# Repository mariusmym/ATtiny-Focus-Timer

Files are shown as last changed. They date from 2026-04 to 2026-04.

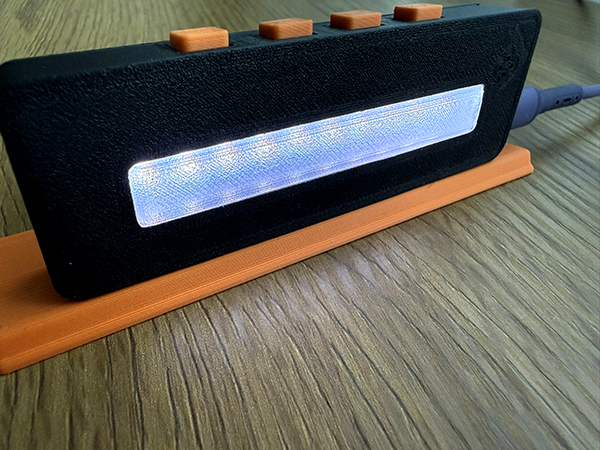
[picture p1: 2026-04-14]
images/IMG_0689.jpg

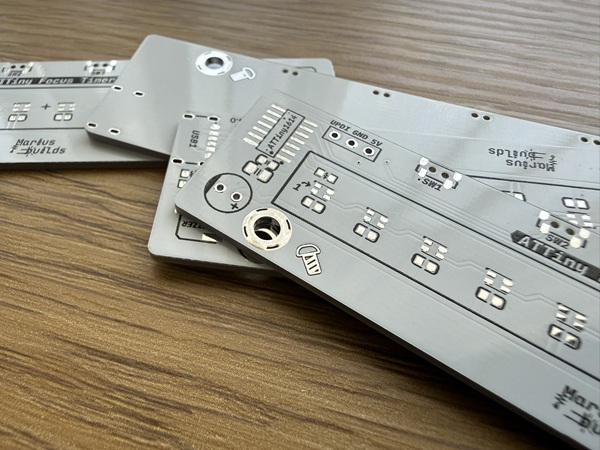
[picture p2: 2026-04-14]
images/IMG_0471.JPEG

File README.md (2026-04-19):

# ATTiny Focus Timer

A minimal, distraction-free focus timer built around the **ATtiny1614** microcontroller. Press a button, pick a duration, and get back to work - 10 WS2812B LEDs show your progress as a filling bar, then gently pulse and beep when time is up.

Created by **@marius.builds**

FocusTimer

---

## How It Works

The timer cycles through four states:

| State | LEDs | Sound |
|---|---|---|
| **Idle** | All LEDs glow white at low brightness | — |
| **Running** | Green progress bar fills one LED at a time | — |
| **Completed** | All LEDs pulse green (20 s grace period) | Finish melody (bee-beep-bee-beep) |
| **Alerting** | All LEDs pulse red | Short beep every 2 seconds |

**Buttons:**
- **In Idle** — each of the 4 buttons starts a preset timer (10 / 20 / 30 / 60 min).
- **In Running** — any button cancels and resets.
- **In Completed or Alerting** — any button acknowledges and returns to Idle.

## Hardware

| Component | Qty | Notes |
|---|---|---|
| ATtiny1614 | 1 | Programmed via megaTinyCore + UPDI |
| WS2812B / NeoPixel LEDs | 10 | Directly driven from PA3 |
| Tactile push buttons | 4 | Connected to PB0–PB3, using internal pull-ups |
| Passive piezo buzzer | 1 | Driven from PA6 via `tone()` |



### Pin Mapping

```
PA3  →  NeoPixel data
PA6  →  Piezo buzzer
PB0  →  Button 1  (10 min)
PB1  →  Button 2  (20 min)
PB2  →  Button 3  (30 min)
PB3  →  Button 4  (60 min)
```

## Software

### Dependencies

- **[megaTinyCore](https://github.com/SpenceKonde/megaTinyCore)** — Arduino core for modern tinyAVR (ATtiny x04/x14/x24 series)
- **tinyNeoPixel_Static** — included with megaTinyCore; lightweight NeoPixel driver for tinyAVR

### Building & Flashing

1. Install **megaTinyCore** via the Arduino IDE Boards Manager.
2. Select **ATtiny1614** as the target board.
3. Set the programmer to **CH340 UPDI** (or whichever UPDI method you use).
4. Open `ATTiny-FocusTimer-V2_1.ino` and upload.

### Configuration

All tunable parameters live at the top of the sketch — no need to dig through logic:

```c
// Timer durations (minutes)
TIMER_1_MINUTES  = 10;
TIMER_2_MINUTES  = 20;
TIMER_3_MINUTES  = 30;
TIMER_4_MINUTES  = 60;

// Behavior
GRACE_MS         = 20000;   // completed → alerting delay (ms)
BEEP_EVERY_MS    = 2000;    // alert beep interval (ms)

// LED brightness (0–255)
IDLE_BRIGHTNESS  = 20;
RUN_BRIGHTNESS   = 120;
PULSE_MIN        = 30;
PULSE_MAX        = 160;
```

For quick bench testing, uncomment the shorter timer values (1 / 2 / 3 / 5 min) already provided in the sketch.

## State Machine

```
         ┌──────────────────────────────────┐
         │           any button             │
         ▼                                  │
      ┌──────┐   button press   ┌─────────┐ │
      │ IDLE │ ───────────────▶│ RUNNING  │ │
      └──────┘                  └────┬────┘ │
         ▲                          │       │
         │ any button        timer done     │
         │                          │       │
    ┌────┴─────┐  grace timeout ┌───▼───────┤
    │ ALERTING │◀──────────────│ COMPLETED  │
    └──────────┘               └────────────┘
```

## Enclosure

The project includes a 3D-printed case designed to house the PCB, LEDs, and buttons in a compact, desk-friendly form factor. The STL files are located in the `case/` folder of this repository. They were designed for FDM printing with no supports needed. There are two types of top case formats. One of them is a one piece design (you have to keep in mind that in order for the LEDs light to go through you have to print the case in bright colors, ideally in white) and the other one that have a cutout for LEDs. The second one lets you print the case in any color because it have a LED COVER that you can print in transparent or any bright color.
If you'd like to tweak the design, the original CAD is included as well (in .f3z format).

An external link for the case can also be found here : https://www.printables.com/model/1689049-attiny-focus-timer-case

## PCB

Full fabrication files are provided in the `pcb/` folder so you can order your own boards:

- **Gerber files** — ready to upload to JLCPCB, PCBWay, or any other fab house.
- **BOM (Bill of Materials)** — a spreadsheet listing every component with values, footprints, and reference designators.
- **Schematic**

## License

This project is licensed under the MIT License.
Feel free to use, modify, and share. Attribution appreciated.

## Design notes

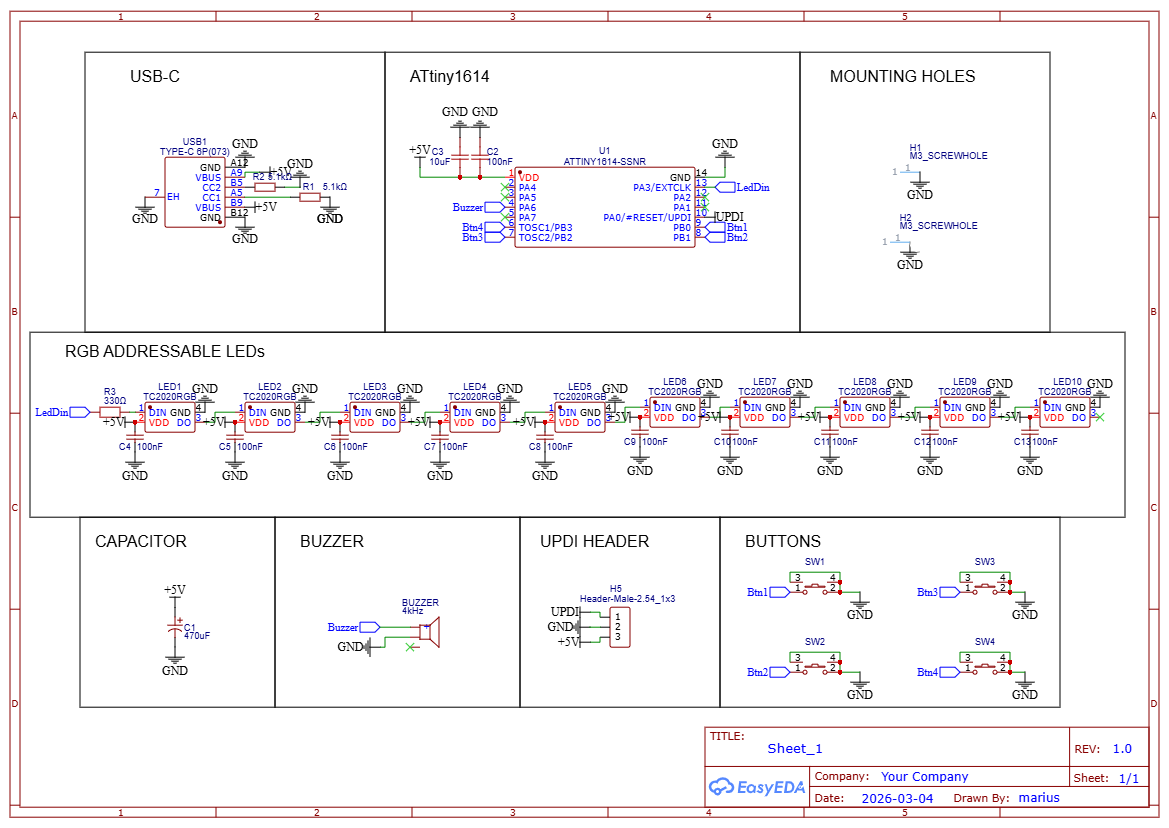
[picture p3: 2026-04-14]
pcb/Schematic_ATTiny_FocusTimer_2026-04-14.png

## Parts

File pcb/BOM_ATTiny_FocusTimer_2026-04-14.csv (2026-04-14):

ID | Name | Designator | Footprint | Quantity | Manufacturer Part | Manufacturer | Supplier | Supplier Part
1 | 100nF | C13 | C_0603_S | 1 | C0603C104K5RACAUTO | KEMET(基美) | LCSC | C129621
2 | 330Ω | R3 | R_0603_S_MYM | 1 | SCR0603F330R | VO(翔胜) | LCSC | C3016255
3 | 4kHz | BUZZER | BUZ-SMD_FST-5030 | 1 | FUET-5030 | FUET(福声科技) | LCSC | C391031
4 | 470uF | C1 | CAP-TH_BD6.0-P2.50-D0.5-FD | 1 | CD110477M1A0607VFL | HRK(鸿瑞凯电子) | LCSC | C7499930
5 | 100nF | C2 | C_0603_S | 1 | CC0603KRX7R9BB104 | YAGEO(国巨) | LCSC | C14663
6 | 10uF | C3 | C_0805 | 1 | CL21A106KAYNNNE | SAMSUNG(三星) | LCSC | C15850
7 | 100nF | C4,C5,C6,C7,C8,C9,C10,C11,C12 | C0603 | 9 | C0603C104K5RACAUTO | KEMET(基美) | LCSC | C129621
8 | Header-Male-2.54_1x3 | H5 | HDR-TH_3P-P2.54-V-M-1 | 1 | 2.54-1*3P针 | BOOMELE(博穆精密) | LCSC | C49257
9 | TC2020RGB | LED1,LED2,LED3,LED4,LED5,LED6,LED7,LED8,LED9,LED10 | LED-SMD_4P-L2.1-W2.1-TL_TC2020RGB | 10 | TX1812ZN | TCWIN(天成) | LCSC | C784563
10 | TS24CA 250GF 013 | SW1,SW2,SW3,SW4 | SW-SMD_L4.7-W3.5-P3.35-EH | 4 | TS24CA 250gf 013 | SHOU HAN(首韩) | LCSC | C5373430
11 | ATTINY1614-SSNR | U1 | SOIC-14_L8.7-W3.9-P1.27-LS6.0-BL | 1 | ATTINY1614-SSNR | MICROCHIP(美国微芯) | LCSC | C481364
12 | TYPE-C 6P(073) | USB1 | TYPE-C-SMD_TYPE-C-6P-073 | 1 | TYPE-C 6P(073) | SHOU HAN(首韩) | LCSC | C668623
13 | 5.1kΩ | R1,R2 | R_0603_S_MYM | 2 | RTT03512JTP | RALEC(旺诠) | LCSC | C103696

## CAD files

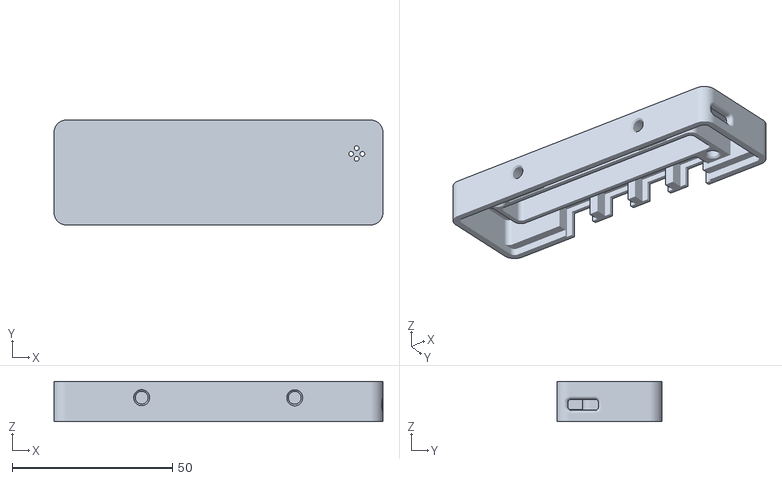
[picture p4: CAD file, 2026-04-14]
case/stl files/TOP-CASE-FULL-FACE.stl
102.8 x 32.8 x 12.6

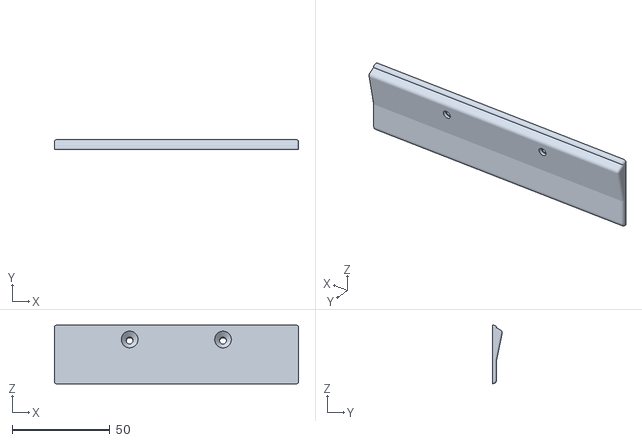
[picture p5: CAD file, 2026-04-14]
case/stl files/DESKTOP-BASE.stl
125.0 x 4.90 x 30.0

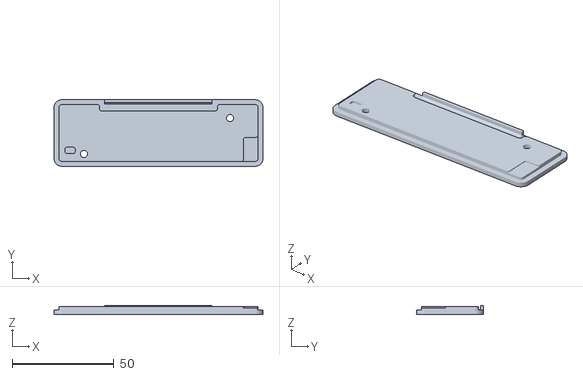
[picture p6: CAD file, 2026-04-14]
case/stl files/BACK-COVER.stl
102.8 x 32.8 x 4.20

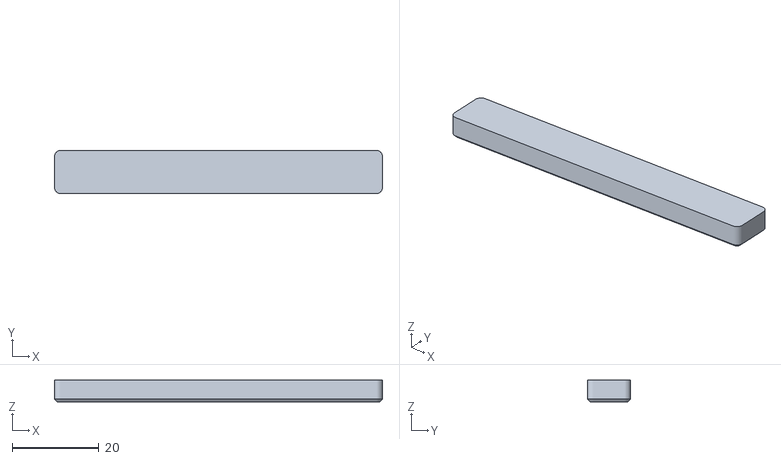
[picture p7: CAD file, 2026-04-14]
case/stl files/LED-COVER.stl
75.7 x 9.97 x 5.00

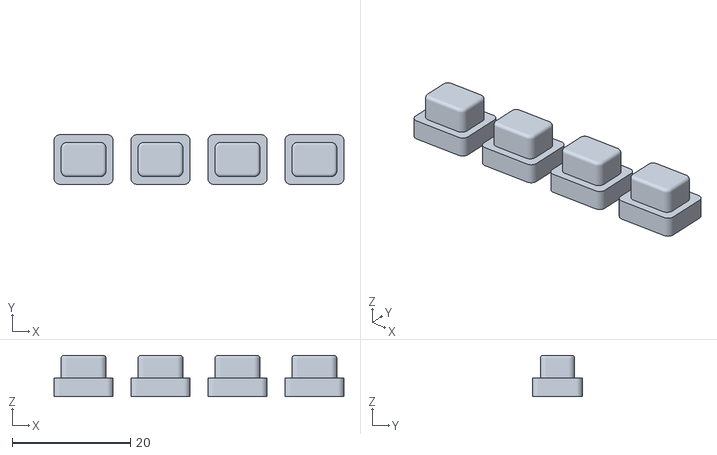
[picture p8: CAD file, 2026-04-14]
case/stl files/BUTTONSv3.stl
49.0 x 8.40 x 7.00

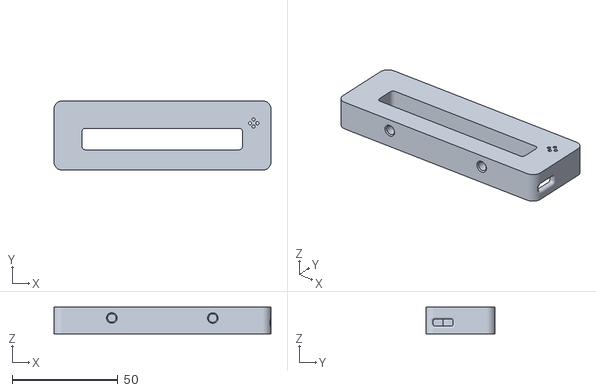
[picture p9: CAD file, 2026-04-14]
case/stl files/TOP-CASE-LED-CUTOUT.stl
102.8 x 32.8 x 12.6

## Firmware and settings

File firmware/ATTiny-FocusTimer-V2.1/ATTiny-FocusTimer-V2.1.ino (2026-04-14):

#include <tinyNeoPixel_Static.h>

// =====================================================
// Focus Timer for ATtiny1614 + megaTinyCore v2.1
// by @marius.builds
// 06.04.2026
// -----------------------------------------------------
// Hardware:
//   - 10x WS2812B / NeoPixel LEDs
//   - 4 buttons
//   - 1 passive piezo buzzer
//
// States:
//   IDLE       = all LEDs are in idle color
//   RUNNING    = green progress bar fills over time
//   COMPLETED  = all LEDs pulse green for a grace period
//   ALERTING   = all LEDs pulse red + short beep every 2 seconds
//
// Button behavior:
//   - In IDLE: buttons start timers
//   - In RUNNING: any button cancels and resets
//   - In COMPLETED / ALERTING: any button acknowledges and resets
//
// Sounds:
//   - Button press: short click
//   - Cancel/reset: longer "beeeep"
//   - Timer finished: bee - beep - bee - beep
//   - Alerting: repeating short beep every 2 seconds
// =====================================================


// ---------- Hardware ----------
#define NUMLEDS     10
#define LED_PIN     PIN_PA3
#define BUZZER_PIN  PIN_PA6

#define BTN_1       PIN_PB0
#define BTN_2       PIN_PB1
#define BTN_3       PIN_PB2
#define BTN_4       PIN_PB3


// ---------- Timer values ----------
static const uint32_t TIMER_1_MINUTES = 10;   // button 1 - SW1
static const uint32_t TIMER_2_MINUTES = 20;   // button 2 - SW2
static const uint32_t TIMER_3_MINUTES = 30;   // button 3 - SW3
static const uint32_t TIMER_4_MINUTES = 60;   // button 4 - SW4

// For quick testing, you can temporarily use:
//static const uint32_t TIMER_1_MINUTES = 1;
//static const uint32_t TIMER_2_MINUTES = 2;
//static const uint32_t TIMER_3_MINUTES = 3;
//static const uint32_t TIMER_4_MINUTES = 5;


// ---------- Behavior ----------
static const uint32_t GRACE_MS      = 20000UL; // completed/grace period
static const uint16_t BEEP_EVERY_MS = 2000;    // alert beep interval


// ---------- LED brightness ----------
static const uint8_t IDLE_BRIGHTNESS = 20;   // low idle brightness
static const uint8_t RUN_BRIGHTNESS  = 120;
static const uint8_t PULSE_MIN       = 30;
static const uint8_t PULSE_MAX       = 160;


// ---------- Colors (R,G,B) ----------
static const uint8_t IDLE_R   = 74;
static const uint8_t IDLE_G   = 238;
static const uint8_t IDLE_B   = 227;

static const uint8_t RUN_R    = 0;
static const uint8_t RUN_G    = 140;
static const uint8_t RUN_B    = 0;

static const uint8_t ALERT_R  = 140;
static const uint8_t ALERT_G  = 0;
static const uint8_t ALERT_B  = 0;


// ---------- Buzzer tones ----------
static const uint16_t CLICK_FREQ      = 3500;
static const uint16_t CLICK_LEN_MS    = 40;

static const uint16_t CANCEL_FREQ     = 1800;
static const uint16_t CANCEL_LEN_MS   = 300;

// Finish alarm: bee - beep - bee - beep
static const uint16_t FINISH_FREQ_LONG   = 1800;
static const uint16_t FINISH_FREQ_SHORT  = 2600;
static const uint16_t FINISH_LONG_MS     = 260;
static const uint16_t FINISH_SHORT_MS    = 80;
static const uint16_t FINISH_GAP_MS      = 70;

static const uint16_t ALERT_FREQ      = 2200;
static const uint16_t ALERT_LEN_MS    = 120;


// ---------- NeoPixel buffer ----------
byte pixels[NUMLEDS * 3];
tinyNeoPixel leds(NUMLEDS, LED_PIN, NEO_GRB + NEO_KHZ800, pixels);


// ---------- State machine ----------
enum TimerState : uint8_t {
  STATE_IDLE = 0,
  STATE_RUNNING,
  STATE_COMPLETED,
  STATE_ALERTING
};

TimerState state = STATE_IDLE;


// ---------- Timer state variables ----------
uint32_t timerStartMs     = 0;
uint32_t timerDurationMs  = 0;
uint32_t completedStartMs = 0;


// ---------- Buzzer state ----------
uint32_t lastBeepMs  = 0;
uint32_t beepOffAtMs = 0;
bool beepActive      = false;


// ---------- Finish alarm sequencer ----------
bool finishSequenceActive = false;
uint8_t finishSequenceStep = 0;
uint32_t finishSequenceAtMs = 0;


// ---------- Button debounce ----------
static const uint16_t DEBOUNCE_MS = 25;
uint8_t  lastRawButtons = 0;
uint8_t  stableButtons  = 0;
uint32_t lastBounceMs   = 0;


// =====================================================
// Button helpers
// =====================================================

uint8_t readButtonsRaw() {
  uint8_t m = 0;

  if (!digitalRead(BTN_1)) m |= (1 << 0);
  if (!digitalRead(BTN_2)) m |= (1 << 1);
  if (!digitalRead(BTN_3)) m |= (1 << 2);
  if (!digitalRead(BTN_4)) m |= (1 << 3);

  return m;
}


uint8_t getButtonsPressed() {
  uint32_t now = millis();
  uint8_t raw = readButtonsRaw();

  if (raw != lastRawButtons) {
    lastRawButtons = raw;
    lastBounceMs = now;
  }

  if ((now - lastBounceMs) >= DEBOUNCE_MS) {
    uint8_t prevStable = stableButtons;
    stableButtons = raw;
    return (stableButtons & ~prevStable);
  }

  return 0;
}


// =====================================================
// LED helpers
// =====================================================

static inline uint8_t scale8(uint8_t v, uint8_t scale) {
  return (uint16_t(v) * uint16_t(scale)) >> 8;
}


void setAll(uint8_t r, uint8_t g, uint8_t b, uint8_t brightness) {
  uint8_t rr = scale8(r, brightness);
  uint8_t gg = scale8(g, brightness);
  uint8_t bb = scale8(b, brightness);

  for (uint8_t i = 0; i < NUMLEDS; i++) {
    leds.setPixelColor(i, rr, gg, bb);
  }

  leds.show();
}


void showIdle() {
  setAll(IDLE_R, IDLE_G, IDLE_B, IDLE_BRIGHTNESS);
}


void showRunningProgress(uint32_t elapsed, uint32_t total) {
  if (elapsed > total) elapsed = total;

  uint8_t lit = (total == 0) ? 0 : (uint32_t(elapsed) * NUMLEDS) / total;

  for (uint8_t i = 0; i < NUMLEDS; i++) {
    leds.setPixelColor(i, 0, 0, 0);
  }

  uint8_t rr = scale8(RUN_R, RUN_BRIGHTNESS);
  uint8_t gg = scale8(RUN_G, RUN_BRIGHTNESS);
  uint8_t bb = scale8(RUN_B, RUN_BRIGHTNESS);

  for (uint8_t i = 0; i < lit && i < NUMLEDS; i++) {
    leds.setPixelColor(i, rr, gg, bb);
  }

  leds.show();
}


uint8_t triangleWave8(uint32_t tMs, uint16_t periodMs) {
  uint32_t p = periodMs;
  uint32_t x = tMs % p;
  uint32_t half = p / 2;

  if (half == 0) return 0;

  if (x < half) {
    return (uint32_t(x) * 255) / half;
  } else {
    return (uint32_t(p - x) * 255) / half;
  }
}


void showPulsingAll(uint8_t r, uint8_t g, uint8_t b, uint16_t periodMs) {
  uint8_t wave = triangleWave8(millis(), periodMs);
  uint8_t brightness = PULSE_MIN + (uint16_t(wave) * (PULSE_MAX - PULSE_MIN)) / 255;
  setAll(r, g, b, brightness);
}


void showCompletedPulse() {
  showPulsingAll(RUN_R, RUN_G, RUN_B, 1000);
}


void showAlertingPulse() {
  showPulsingAll(ALERT_R, ALERT_G, ALERT_B, 1000);
}


// =====================================================
// Buzzer helpers
// =====================================================

void buzzerStartBeep(uint16_t freq, uint16_t durationMs) {
  tone(BUZZER_PIN, freq);
  beepActive = true;
  beepOffAtMs = millis() + durationMs;
}


void buzzerUpdate() {
  if (beepActive && (int32_t)(millis() - beepOffAtMs) >= 0) {
    noTone(BUZZER_PIN);
    beepActive = false;
  }
}


void buzzerStop() {
  noTone(BUZZER_PIN);
  beepActive = false;
}


// =====================================================
// Finish alarm sequencer
// Pattern: bee - beep - bee - beep
// =====================================================

void startFinishAlarm() {
  finishSequenceActive = true;
  finishSequenceStep = 0;
  finishSequenceAtMs = millis();

  buzzerStartBeep(FINISH_FREQ_LONG, FINISH_LONG_MS);
}


void updateFinishAlarm() {
  if (!finishSequenceActive) return;

  uint32_t now = millis();

  switch (finishSequenceStep) {
    case 0:
      if (!beepActive) {
        finishSequenceStep = 1;
        finishSequenceAtMs = now;
      }
      break;

    case 1:
      if ((now - finishSequenceAtMs) >= FINISH_GAP_MS) {
        buzzerStartBeep(FINISH_FREQ_SHORT, FINISH_SHORT_MS);
        finishSequenceStep = 2;
      }
      break;

    case 2:
      if (!beepActive) {
        finishSequenceStep = 3;
        finishSequenceAtMs = now;
      }
      break;

    case 3:
      if ((now - finishSequenceAtMs) >= FINISH_GAP_MS) {
        buzzerStartBeep(FINISH_FREQ_LONG, FINISH_LONG_MS);
        finishSequenceStep = 4;
      }
      break;

    case 4:
      if (!beepActive) {
        finishSequenceStep = 5;
        finishSequenceAtMs = now;
      }
      break;

    case 5:
      if ((now - finishSequenceAtMs) >= FINISH_GAP_MS) {
        buzzerStartBeep(FINISH_FREQ_SHORT, FINISH_SHORT_MS);
        finishSequenceStep = 6;
      }
      break;

    case 6:
      if (!beepActive) {
        finishSequenceActive = false;
      }
      break;
  }
}


// =====================================================
// Timer state control
// =====================================================

void startTimerMinutes(uint32_t minutes) {
  timerDurationMs = minutes * 60UL * 1000UL;
  timerStartMs = millis();
  state = STATE_RUNNING;
}


void cancelAndReset() {
  finishSequenceActive = false;
  buzzerStartBeep(CANCEL_FREQ, CANCEL_LEN_MS);
  state = STATE_IDLE;
  showIdle();
}


void enterCompleted() {
  state = STATE_COMPLETED;
  completedStartMs = millis();
  startFinishAlarm();
}


void enterAlerting() {
  state = STATE_ALERTING;
  lastBeepMs = millis() - BEEP_EVERY_MS;
  finishSequenceActive = false;
  buzzerStop();
}


// =====================================================
// Setup
// =====================================================

void setup() {
  pinMode(LED_PIN, OUTPUT);

  pinMode(BUZZER_PIN, OUTPUT);
  buzzerStop();

  pinMode(BTN_1, INPUT_PULLUP);
  pinMode(BTN_2, INPUT_PULLUP);
  pinMode(BTN_3, INPUT_PULLUP);
  pinMode(BTN_4, INPUT_PULLUP);

  leds.begin();
  delay(20);

  showIdle();

  // Optional startup beep
  tone(BUZZER_PIN, 2000);
  delay(80);
  noTone(BUZZER_PIN);
}


// =====================================================
// Main loop
// =====================================================

void loop() {
  uint32_t now = millis();
  uint8_t pressed = getButtonsPressed();

  if (pressed) {
    if (state == STATE_IDLE) {
      buzzerStartBeep(CLICK_FREQ, CLICK_LEN_MS);

      if (pressed & (1 << 0)) {
        startTimerMinutes(TIMER_1_MINUTES);
      }
      else if (pressed & (1 << 1)) {
        startTimerMinutes(TIMER_2_MINUTES);
      }
      else if (pressed & (1 << 2)) {
        startTimerMinutes(TIMER_3_MINUTES);
      }
      else if (pressed & (1 << 3)) {
        startTimerMinutes(TIMER_4_MINUTES);
      }
    } else {
      cancelAndReset();
    }
  }

  switch (state) {
    case STATE_IDLE:
      break;

    case STATE_RUNNING: {
      uint32_t elapsed = now - timerStartMs;
      showRunningProgress(elapsed, timerDurationMs);

      if (elapsed >= timerDurationMs) {
        enterCompleted();
      }
    } break;

    case STATE_COMPLETED:
      showCompletedPulse();

      if ((now - completedStartMs) >= GRACE_MS) {
        enterAlerting();
      }
      break;

    case STATE_ALERTING:
      showAlertingPulse();

      if ((now - lastBeepMs) >= BEEP_EVERY_MS) {
        lastBeepMs = now;
        buzzerStartBeep(ALERT_FREQ, ALERT_LEN_MS);
      }
      break;
  }

  buzzerUpdate();
  updateFinishAlarm();

  delay(10);
}
